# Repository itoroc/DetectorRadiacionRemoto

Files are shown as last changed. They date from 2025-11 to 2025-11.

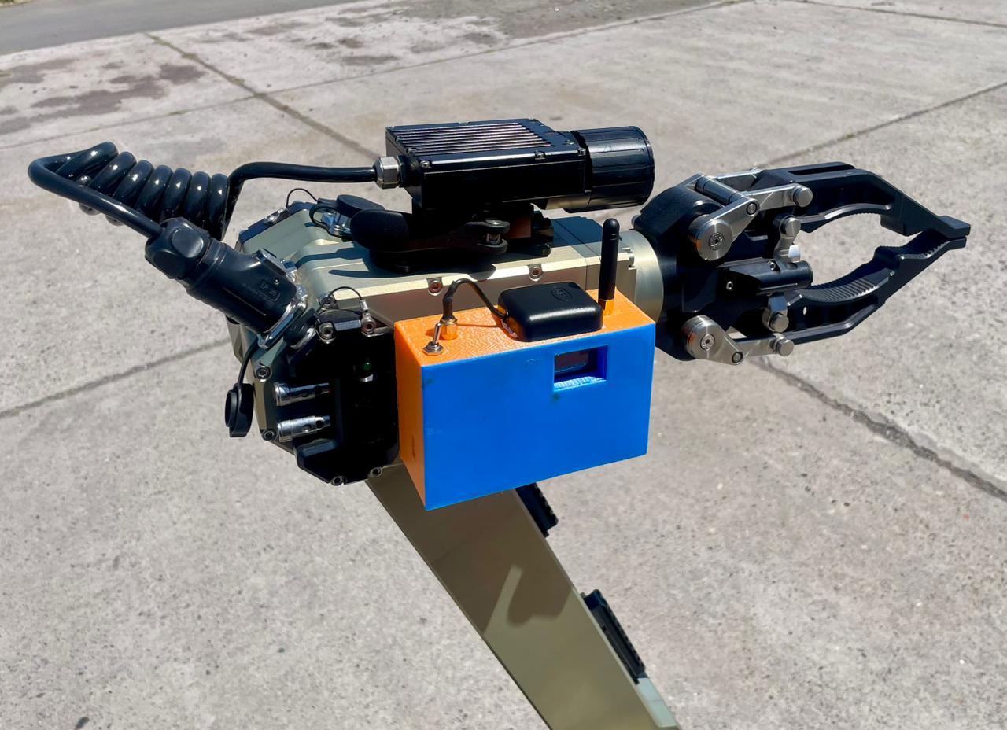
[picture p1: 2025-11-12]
Fotografías/05_MontajeRobot_Detalle.jpeg

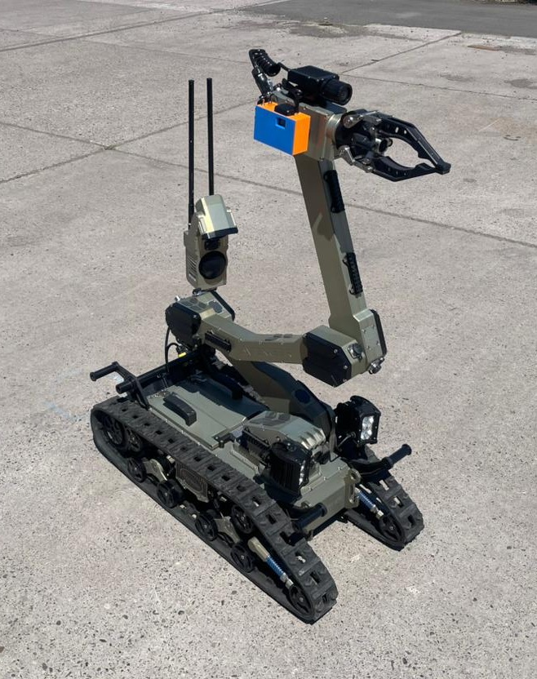
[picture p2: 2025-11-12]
Fotografías/04_MontajeRobot_General.jpeg

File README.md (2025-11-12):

La solución propuesta es un equipo tecnológico de detección y localización de fuentes de radiación ionizante de tipo electromagnética (gamma y rayos X), cuya característica principal es su capacidad de despliegue remoto, al estar conformado por 2 elementos de hardware comunicados inalámbricamente entre sí: La Consola de Control y visualización, que consiste en una computadora embebida montada en una maleta compacta, que incorpora una pantalla táctil y que da acceso a un dashboard interactivo con información en tiempo real de los parámetros recibidos desde el segundo elemento de hardware, el Detector Remoto, el cual consiste en un microcontrolador con un sensor de radiación ionizante y un módulo de GNSS, el cual se comunica mediante tecnología LoRa y MQTT con la consola de control y cuenta con un sistema de montaje para vehículos no tripulados, tipo riel picatinny. En cuanto a la interfaz gráfica, esta muestra un mapa de radiación, cuya intensidad se representa en diferentes colores sobre el mapa, otorgando la capacidad de conocer el estado radiológico de un entorno durante una intervención de emergencia radiológica, mostrando también valores de tasa de dosis y cuentas por minuto, entregando información útil para la toma de decisiones por parte de los primeros intervinientes.

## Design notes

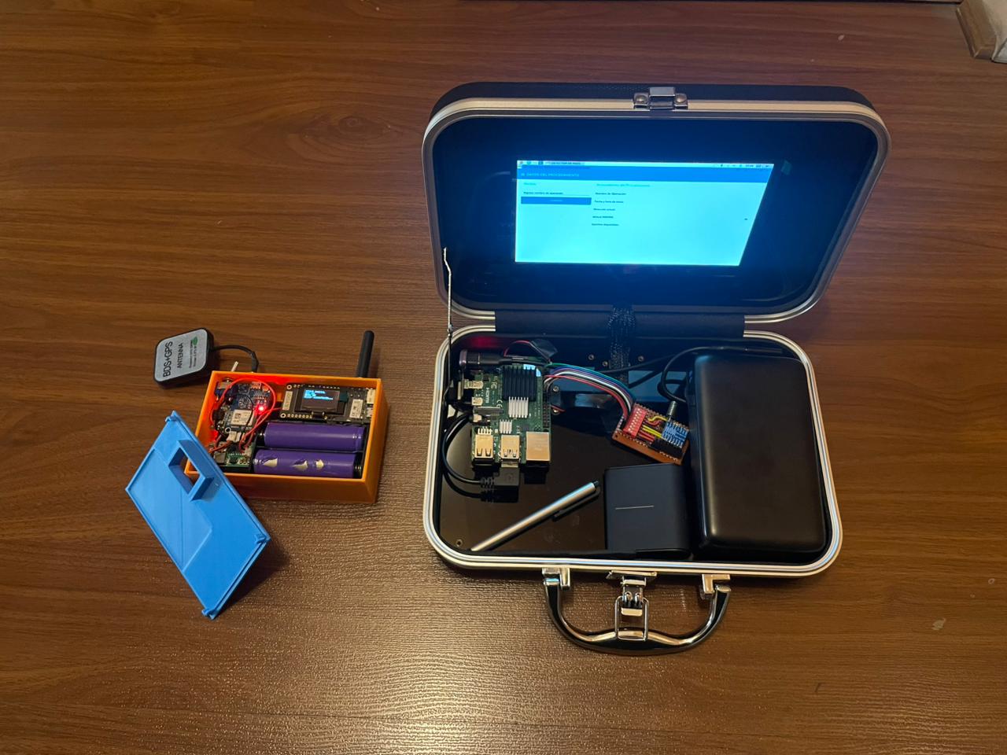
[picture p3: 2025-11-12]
Fotografías/01_ConsolaYDetector.jpeg

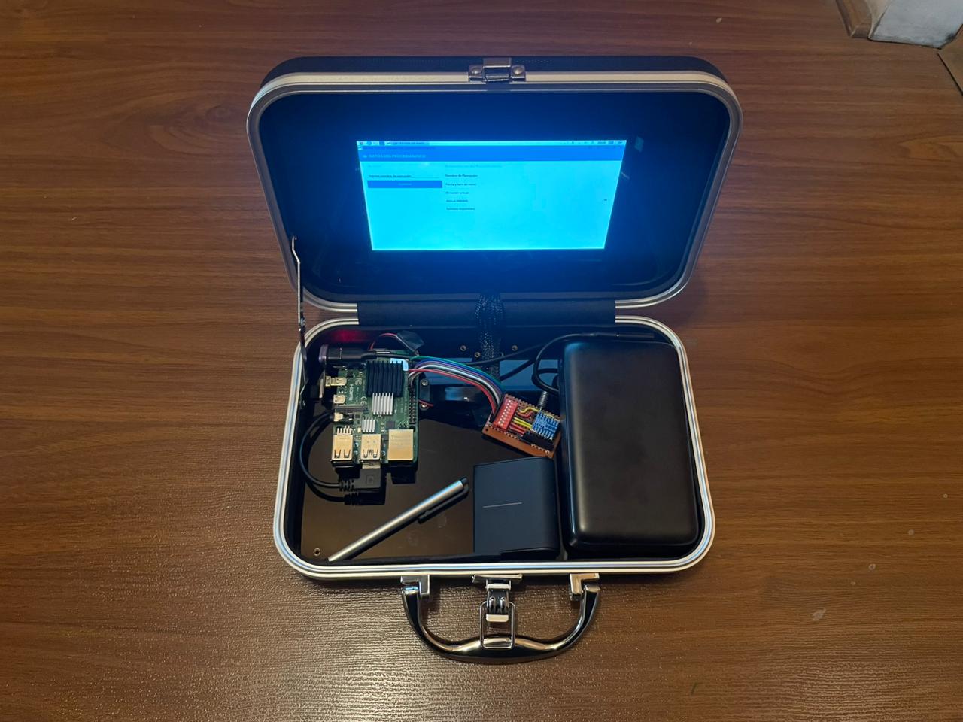
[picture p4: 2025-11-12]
Fotografías/02_ConsolaControl.jpeg

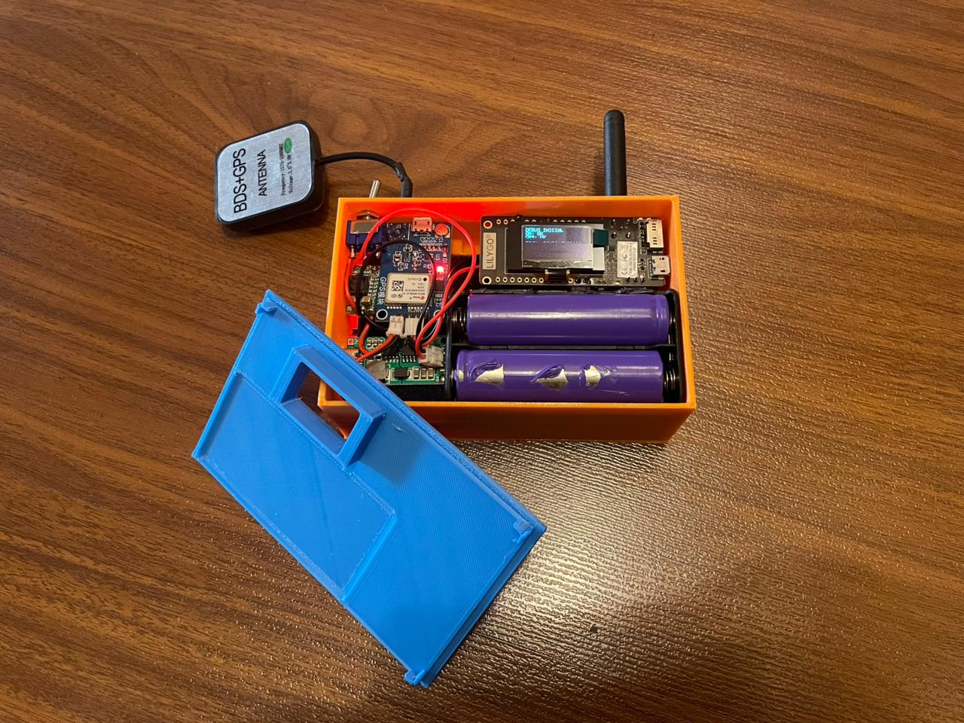
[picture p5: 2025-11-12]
Fotografías/03_DetectorRemoto.jpeg

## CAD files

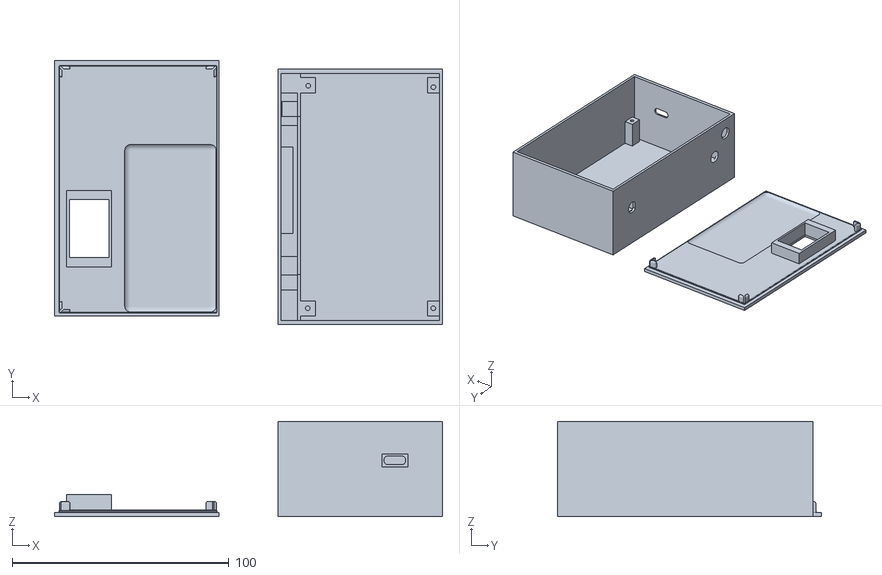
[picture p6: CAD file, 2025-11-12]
Diseño3D_Carcasa/DetectorRemoto.stl
179.0 x 122.0 x 44.0

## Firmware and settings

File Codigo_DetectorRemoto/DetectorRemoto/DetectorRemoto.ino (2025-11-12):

// LIBRERIAS
#include <SPI.h>
#include <Wire.h>
#include <LoRa.h>
#include <Adafruit_GFX.h>
#include <Adafruit_SSD1306.h>
#include <TinyGPS++.h>

// CONFIGURACION LORA32
#define LORA_SCK  5
#define LORA_MISO 19
#define LORA_MOSI 27
#define LORA_SS   18
#define LORA_RST  14
#define LORA_DIO0 26

// CONFIGURACION OLED
#define SCREEN_WIDTH 128
#define SCREEN_HEIGHT 64
Adafruit_SSD1306 display(SCREEN_WIDTH, SCREEN_HEIGHT, &Wire, -1);

// CONFIGURACION GEIGER MULLER
#define GEIGER_PIN 34
#define LOG_PERIOD 15000
#define MAX_PERIOD 60000
unsigned long counts = 0, cpm = 0;
unsigned int multiplier = MAX_PERIOD / LOG_PERIOD;
unsigned long previousMillis = 0;

// CONFIGURACION GPS
#define RXD2 12
#define TXD2 13
#define GPS_BAUD 9600
TinyGPSPlus gps;
HardwareSerial gpsSerial(2);



// Contador de envios
unsigned int envioNum = 1;

// Dosis: 151 CPM = 1 uSv/h
const float CPM_PER_uSvPH = 512.0f;
double dosis_uSv = 0.0;
unsigned long lastDoseMillis = 0;


// CONFIGURACION ACK/CRC

static const uint16_t ACK_TIMEOUT_MS = 800;

// CRC16-CCITT (poly 0x1021, init 0xFFFF)
uint16_t crc16_ccitt(const uint8_t* data, size_t len) {
  uint16_t crc = 0xFFFF;
  for (size_t i = 0; i < len; i++) {
    crc ^= (uint16_t)data[i] << 8;
    for (uint8_t j = 0; j < 8; j++) {
      if (crc & 0x8000) crc = (uint16_t)((crc << 1) ^ 0x1021);
      else crc <<= 1;
    }
  }
  return crc;
}

// append ";CRC=XXXX" to payload (CRC over text before CRC)
String append_crc16_ccitt(const String& payload_without_crc) {
  uint16_t c = crc16_ccitt((const uint8_t*)payload_without_crc.c_str(), payload_without_crc.length());
  char buf[16];
  snprintf(buf, sizeof(buf), ";CRC=%04X", c);
  String out = payload_without_crc;
  out += String(buf);
  return out;
}

String twoDigits(uint16_t n){
  char b[4];
  n = n % 100;
  snprintf(b, sizeof(b), "%02u", n);
  return String(b);
}

bool waitForAck(uint16_t seq, uint16_t timeout_ms){
  // drenar paquetes residuales
  int ps;
  while ((ps = LoRa.parsePacket())) { while (LoRa.available()) LoRa.read(); }
  unsigned long t0 = millis();
  LoRa.receive();
  while (millis() - t0 < timeout_ms){
    int packetSize = LoRa.parsePacket();
    if (packetSize){
      String r = "";
      while (LoRa.available()) r += (char)LoRa.read();
      if (r.startsWith("ACK:")){
        int comma = r.indexOf(',');
        String seqStr = (comma > 4) ? r.substring(4, comma) : r.substring(4);
        int rx = seqStr.toInt();
        bool ok = (r.indexOf(",OK") >= 0);
        if (rx == (int)(seq % 100)) return ok;
      }
    }
    delay(1);
  }
  return false;
}


// CONFIGURACION COLA FIFO

static const uint8_t  QUEUE_MAX = 40;
String   q_msg[QUEUE_MAX];
uint16_t q_seq[QUEUE_MAX];
uint8_t  q_head = 0, q_tail = 0, q_size = 0;

bool q_enqueue(const String& msg, uint16_t seq){
  if (q_size >= QUEUE_MAX){
    // drop oldest
    q_head = (q_head + 1) % QUEUE_MAX;
    q_size--;
  }
  q_msg[q_tail] = msg;
  q_seq[q_tail] = seq;
  q_tail = (q_tail + 1) % QUEUE_MAX;
  q_size++;
  return true;
}

bool q_is_empty(){ return q_size == 0; }

void q_front(String& msg, uint16_t& seq){
  msg = q_msg[q_head];
  seq = q_seq[q_head];
}

void q_pop(){
  if (q_size == 0) return;
  q_head = (q_head + 1) % QUEUE_MAX;
  q_size--;
}

// slots de reintento tras un envio normal OK
const uint16_t SLOT_OFFSETS_MS[4] = { 3000, 6000, 9000, 12000 };
bool slot_used[4] = {false,false,false,false};
bool cycle_ok = false;
unsigned long cycle_start_ms = 0;

// record de ultima medicion para refrescar pantalla
String last_lat = "0.0", last_lon = "0.0", last_alt = "0.0", last_sat = "0";
unsigned long last_cpm = 0;
float last_tasa = 0.0f;

void IRAM_ATTR tube_impulse() { counts++; }

// Escribir datos en pantalla
void draw_screen_line1(bool ok_flag){
  display.clearDisplay();
  display.setCursor(0, 0);
  display.println(String("Envio N. ") + twoDigits(envioNum) + (ok_flag ? " OK " : " BAD ") + "[" + twoDigits((uint16_t)(q_size % 100)) + "]");
  display.println("Lat: " + last_lat);
  display.println("Lon: " + last_lon);
  display.println("Alt: " + last_alt + " m");
  display.println("Sat: " + last_sat);
  display.println("CPM: " + String(last_cpm));
  display.println("TdD: " + String(last_tasa, 4) + " uSv/h");
  display.println("Dos: " + String(dosis_uSv, 4) + " uSv");
  display.display();
}

// Formateo de fecha/hora GPS
String gps_date_str(){
  if (!gps.date.isValid()) return "0000-00-00";
  int y = gps.date.year();
  int m = gps.date.month();
  int d = gps.date.day();
  char b[11];
  snprintf(b, sizeof(b), "%04d-%02d-%02d", y, m, d);
  return String(b);
}

String gps_time_str(){
  if (!gps.time.isValid()) return "00:00:00";
  int hh = gps.time.hour();
  int mm = gps.time.minute();
  int ss = gps.time.second();
  char b[9];
  snprintf(b, sizeof(b), "%02d:%02d:%02d", hh, mm, ss);
  return String(b);
}


// DEBUG DE ARRANQUE
void draw_boot_status(bool ok_gm, bool ok_gps, bool ok_lora){
  display.clearDisplay();
  display.setCursor(0,0);
  display.println("DEBUG INICIAL");
  display.println(ok_gm  ? "GM: OK"      : "GM: esperando...");
  display.println(ok_gps ? "GPS: OK"     : "GPS: cargando...");
  display.println(ok_lora? "LORA: OK"    : "LORA: conectando...");
  display.display();
}

// linea de espera con contador: GPS: Wait(XXX s.)
void draw_boot_status_wait(uint16_t secs, bool ok_gm, bool ok_lora){
  display.clearDisplay();
  display.setCursor(0,0);
  display.println("DEBUG INICIAL");
  display.println(ok_gm  ? "GM: OK"      : "GM: esperando...");
  char line[24];
  snprintf(line, sizeof(line), "GPS: Wait(%3u s.)", (unsigned)secs);
  display.println(String(line));
  display.println(ok_lora? "LORA: OK"    : "LORA: conectando...");
  display.display();
}

bool wait_gm_ok(){
  unsigned long base = counts;
  while (true){
    draw_boot_status((counts - base) > 0, false, false);
    if ((counts - base) > 0) return true;
    delay(200);
  }
}

// 2 min de espera para conectar GPS o continúa igual
bool wait_gps_ok(){
  const unsigned long TMAX_MS = 120000UL;
  unsigned long t0 = millis();
  unsigned long lastLog = 0;

  while (true){
    while (gpsSerial.available()) gps.encode(gpsSerial.read());

    double lat = gps.location.lat();
    double lon = gps.location.lng();
    bool havePosNonZero = !(lat == 0.0 && lon == 0.0);
    if (havePosNonZero){
      draw_boot_status(true, true, false);
      return true;
    }

    unsigned long elapsed = millis() - t0;
    if (elapsed >= TMAX_MS){
      draw_boot_status(true, true, false);
      Serial.println("[GPS] timeout 120 s: continuando sin fix (lat/lon==0.0)");
      return true;
    }

    uint16_t secs = (uint16_t)(elapsed / 1000UL);
    draw_boot_status_wait(secs, true, false);

    if (elapsed - lastLog > 2000){
      lastLog = elapsed;
      Serial.print("[GPS] wait "); Serial.print(secs); Serial.print(" s, chars=");
      Serial.print(gps.charsProcessed());
      Serial.print(" sats=");
      if (gps.satellites.isValid()) Serial.println((int)gps.satellites.value());
      else Serial.println(-1);
    }

    delay(150);
  }
}

// HandShake LoRa
bool wait_lora_handshake_ok(){
  const uint16_t seq0 = 0;
  while (true){
    String hello = "HELLO,SEQ=" + twoDigits(seq0);
    LoRa.idle();
    LoRa.beginPacket();
    LoRa.print(hello);
    LoRa.endPacket();
    bool ok = waitForAck(seq0, 800);
    draw_boot_status(true, true, ok);
    if (ok) return true;
    delay(500);
  }
}

// Bucle de configuraciones
void setup() {
  Serial.begin(115200);
  gpsSerial.begin(GPS_BAUD, SERIAL_8N1, RXD2, TXD2);
  pinMode(GEIGER_PIN, INPUT);
  attachInterrupt(GEIGER_PIN, tube_impulse, FALLING);

  if (!display.begin(SSD1306_SWITCHCAPVCC, 0x3C)) { while (1); }
  display.clearDisplay();
  display.setTextSize(1);
  display.setTextColor(WHITE);
  display.setCursor(0, 0);
  display.println("Iniciando LoRa...");
  display.display();

  SPI.begin(LORA_SCK, LORA_MISO, LORA_MOSI, LORA_SS);
  LoRa.setPins(LORA_SS, LORA_RST, LORA_DIO0);

  if (!LoRa.begin(915E6)) {
    display.clearDisplay();
    display.setCursor(0, 0);
    display.println("Fallo LoRa");
    display.display();
    while (1);
  }
  LoRa.setTxPower(20, PA_OUTPUT_PA_BOOST_PIN);
  LoRa.enableCrc();

  // debug inicial bloqueante: GM -> GPS -> LoRa
  draw_boot_status(false, false, false);
  wait_gm_ok();
  wait_gps_ok();
  wait_lora_handshake_ok();

  display.clearDisplay();
  display.setCursor(0, 0);
  display.println("LoRa listo!");
  display.display();

  lastDoseMillis = millis();
  previousMillis = millis();
}

// Envio de datos encolados
void try_send_queue_slots(){
  if (!cycle_ok || q_is_empty()) return;
  unsigned long now = millis();
  for (uint8_t i = 0; i < 4; i++){
    if (slot_used[i]) continue;
    unsigned long slot_time = cycle_start_ms + SLOT_OFFSETS_MS[i];
    if (now >= slot_time){
      if (q_is_empty()) { slot_used[i] = true; continue; }

      String msg; uint16_t seq;
      q_front(msg, seq);

      LoRa.idle();
      LoRa.beginPacket();
      LoRa.print(msg);
      LoRa.endPacket();

      bool ok = waitForAck(seq, 600);
      if (ok){
        q_pop();
        draw_screen_line1(true);
      }
      slot_used[i] = true;
    }
  }
}

void loop() {
  while (gpsSerial.available()) { gps.encode(gpsSerial.read()); }

  // reintentos programados en cola
  try_send_queue_slots();

  unsigned long currentMillis = millis();
  if (currentMillis - previousMillis > LOG_PERIOD) {
    unsigned long dt_ms = currentMillis - lastDoseMillis;
    lastDoseMillis = currentMillis;

    previousMillis = currentMillis;
    cpm = counts * multiplier;
    counts = 0;

    String lat = "0.0";
    String lon = "0.0";
    String alt = "0.0";
    String sat = "0";
    bool gps_ok = false;

    if (gps.location.isValid()) {
      lat = String(gps.location.lat(), 6);
      lon = String(gps.location.lng(), 6);
      alt = String(gps.altitude.meters());
      sat = String(gps.satellites.value());
      // gps_ok si lat/lon no son cero
      gps_ok = !(lat == "0.000000" && lon == "0.000000");
      if (lat == "0.0" && lon == "0.0") gps_ok = false;
    }

    float tasa_uSv_h = (float)cpm / CPM_PER_uSvPH;
    double dt_h = (double)dt_ms / 3600000.0;
    dosis_uSv += (double)tasa_uSv_h * dt_h;

    // guardar ultimos para pantalla
    last_lat = lat; last_lon = lon; last_alt = alt; last_sat = sat;
    last_cpm = cpm; last_tasa = tasa_uSv_h;

    // fecha y hora GPS
    String fstr = gps_date_str();
    String tstr = gps_time_str();

    // payload con DATE/TIME antes de SEQ y CRC
    String core = "todo:" + lat + "," + lon + "," + String(cpm) + "," + alt + "," + sat;
    core += ",DATE=" + fstr + ",TIME=" + tstr;
    core += ",SEQ=" + twoDigits(envioNum);
    String mensaje = append_crc16_ccitt(core);

    // enviar
    LoRa.idle();
    LoRa.beginPacket();
    LoRa.print(mensaje);
    LoRa.endPacket();

    bool ok = waitForAck(envioNum, ACK_TIMEOUT_MS);
    if (!ok) {
      // encolar solo si hay posicion valida (no 0.0)
      if (gps_ok) {
        q_enqueue(mensaje, envioNum);
      }
    }

    // preparar slots de reintento si hubo OK
    if (ok){
      cycle_ok = true;
      cycle_start_ms = currentMillis;
      for (uint8_t i=0;i<4;i++) slot_used[i] = false;
    } else {
      cycle_ok = false;
    }

    // pantalla
    draw_screen_line1(ok);

    Serial.println("Enviado: " + mensaje);
    envioNum++;
    if (envioNum > 99) envioNum = 1;
  }
}

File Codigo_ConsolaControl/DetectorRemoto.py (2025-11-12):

#!/usr/bin/env python3
# Interfaz_Lora_MQTT_ACK_CRC_v4.py
# Receptor con verificacion CRC16-CCITT y ACK:SEQ,OK/ERR
# - Compatible con paquete: todo:lat,lon,cpm,alt,sat,DATE=YYYY-MM-DD,TIME=HH:MM:SS,SEQ=NN;CRC=XXXX
# - Handshake de arranque: responde a "HELLO,SEQ=00" con "ACK:00,OK" (sin exigir CRC)
# - Publica a MQTT solo si CRC valido y prefijo "todo:"

import RPi.GPIO as GPIO
print("[DEBUG] Limpiando configuracion previa de GPIO...")
GPIO.cleanup()

from SX127x.LoRa import LoRa
from SX127x.board_config import BOARD
from SX127x.constants import MODE, BW
import time, re
import paho.mqtt.client as mqtt

# === MQTT ===
BROKER = "localhost"
TOPIC_DATOS = "dispositivos/ESP/datos"

client = mqtt.Client()
try:
    client.connect(BROKER, 1883, 60)
    print(f"[DEBUG] Conectado a MQTT broker en {BROKER}")
except Exception as e:
    print(f"[ERROR] No se pudo conectar a MQTT: {e}")

BOARD.setup()

contador_paquetes = 0

# ---- CRC16-CCITT helpers ----
def crc16_ccitt(data: bytes, poly: int = 0x1021, init_val: int = 0xFFFF) -> int:
    crc = init_val
    for b in data:
        crc ^= (b << 8) & 0xFFFF
        for _ in range(8):
            if crc & 0x8000:
                crc = ((crc << 1) ^ poly) & 0xFFFF
            else:
                crc = (crc << 1) & 0xFFFF
    return crc

def parse_seq_and_crc(payload_str: str):
    m_seq = re.search(r'(?:SEQ\s*[:=]\s*)([A-Fa-f0-9]+)', payload_str)
    seq = m_seq.group(1) if m_seq else None
    m_crc = re.search(r'(?:CRC\s*[:=]\s*)([A-Fa-f0-9]{4})', payload_str)
    rx_crc = m_crc.group(1).upper() if m_crc else None
    core = payload_str[:m_crc.start()].rstrip('; ') if m_crc else payload_str
    calc = f"{crc16_ccitt(core.encode('ascii', errors='ignore')):04X}"
    ok = (rx_crc is not None and rx_crc == calc)
    return core, seq, rx_crc, calc, ok

def build_ack(seq: str | None, ok: bool) -> str:
    s = seq if seq is not None else "NA"
    return f"ACK:{s},{'OK' if ok else 'ERR'}"

def parse_kv_pairs(text: str) -> dict:
    kv = {}
    for m in re.finditer(r'([A-Z]+)\s*=\s*([^,;]+)', text):
        kv[m.group(1).upper()] = m.group(2)
    return kv

class MyLoRa(LoRa):
    def __init__(self):
        super(MyLoRa, self).__init__()
        self.set_mode(MODE.SLEEP)
        self.set_dio_mapping([0,0,0,0,0,0])  # DIO0=RxDone

    def on_rx_done(self):
        global contador_paquetes
        contador_paquetes += 1
        self.set_mode(MODE.STDBY)
        self.clear_irq_flags(RxDone=1, ValidHeader=1, PayloadCrcError=1)

        payload = self.read_payload(nocheck=True)
        mensaje = bytes(payload).decode('utf-8', errors='ignore').strip()
        print(f"[LoRa] Mensaje recibido: {mensaje}")

        # Handshake HELLO sin CRC
        if mensaje.startswith("HELLO"):
            m_seq = re.search(r'(?:SEQ\s*[:=]\s*)([A-Fa-f0-9]+)', mensaje)
            seq = m_seq.group(1) if m_seq else "NA"
            ack = build_ack(seq, True)
            print(f"[DEBUG] Handshake HELLO detectado -> Enviando ACK -> {ack}")
            self._tx_ack_and_listen(ack)
            return

        # CRC
        core, seq, rx_crc, calc, ok = parse_seq_and_crc(mensaje)
        ack = build_ack(seq, ok)
        print(f"[DEBUG] CRC rx={rx_crc} calc={calc} -> {'OK' if ok else 'ERR'}")
        print(f"[DEBUG] Enviando ACK -> {ack}")
        self._tx_ack_and_listen(ack)

        # MQTT publish
        if ok and mensaje.startswith("todo:"):
            contenido = core.replace("todo:", "", 1)
            try:
                client.publish(TOPIC_DATOS, contenido)
                print(f"[MQTT] Publicado en {TOPIC_DATOS} : {contenido}")
            except Exception as e:
                print(f"[WARN] MQTT fallo publicando: {e}")

            partes = contenido.split(",")
            try:
                lat, lon, cpm, alt, sat = partes[:5]
            except Exception:
                lat = lon = cpm = alt = sat = "NA"

            kv = parse_kv_pairs(contenido)
            num = str(contador_paquetes).zfill(3)

            print(f"\n========== DATOS RECIBIDOS ({num}) ==========")
            print(f" Latitud     : {lat}")
            print(f" Longitud    : {lon}")
            print(f" CPM         : {cpm}")
            print(f" Altitud     : {alt} m")
            print(f" Satelites   : {sat}")
            if 'DATE' in kv: print(f" Fecha       : {kv.get('DATE')}")
            if 'TIME' in kv: print(f" Hora        : {kv.get('TIME')}")
            if 'SEQ'  in kv: print(f" SEQ         : {kv.get('SEQ')}")
            print("=============================================\n")
        else:
            if not ok:
                print("[WARN] CRC invalido, no se publica a MQTT")
            else:
                print("[WARN] Mensaje no reconocido, ignorado")

    def _tx_ack_and_listen(self, ack_str: str):
        self.set_dio_mapping([1,0,0,0,0,0])  # DIO0=TxDone
        self.clear_irq_flags(TxDone=1)
        self.write_payload(list(bytearray(ack_str, 'utf-8')))
        self.set_mode(MODE.TX)

    def on_tx_done(self):
        print("[DEBUG] ACK TX done")
        self.clear_irq_flags(TxDone=1)
        self.set_dio_mapping([0,0,0,0,0,0])  # DIO0=RxDone
        self.set_mode(MODE.RXCONT)

# Radio
lora = MyLoRa()
lora.set_mode(MODE.STDBY)
lora.set_freq(915.0)
lora.set_pa_config(pa_select=1, max_power=7, output_power=15)
lora.set_rx_crc(True)
lora.set_spreading_factor(7)
lora.set_coding_rate(5)
lora.set_bw(BW.BW125)
lora.set_mode(MODE.RXCONT)

print("[OK] Receptor LoRa SX127x iniciado y escuchando...")

try:
    while True:
        time.sleep(0.2)
except KeyboardInterrupt:
    print("\n[EXIT] KeyboardInterrupt")
finally:
    BOARD.teardown()
    print("[DEBUG] GPIO y SPI liberados correctamente")
